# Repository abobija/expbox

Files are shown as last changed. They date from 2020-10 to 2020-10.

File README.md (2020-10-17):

# PCB Exposure Box [expbox]

This is repository of PCB Exposure Box [expbox] which uses PIC16F886 for it's brain and shows the time on display made up out of four seven-segment led modules.

Because display is made up out of 4 digits, I have decided to limit **maximum exposure time**, that can be set, to **1 hour** (**59m59s**). Even 1 hour is more than enough, because exposure process takes no more than maximum 10 to 15 minutes.

After the countdown comes to zero, finish of exposure process will be signalized with 1 second of high frequency tone.

### Demo

Making of Exposure Box ... *PCB diy* (https://www.youtube.com/watch?v=g0XoKE_xRvM)

## Microcontroller

Microcontroller used in this project is [**PIC16F886**](https://www.microchip.com/wwwproducts/en/PIC16F886) produced by [Microchip](https://www.microchip.com) company. This MCU has three timers and each timer is assigned to a separated task. **Timer0** is responsible for multiplexing four seven-segment led modules. **Timer1** is shared between tasks for precise time measuring and buttons debouncing. And last, but not least, **Timer2** is in charge of driving piezo speaker with **P**ulse **W**ide **M**odulated signal.

The controller uses an **internal oscillator** and it's set to maximum frequency of **8 MHz**.

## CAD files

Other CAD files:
sketchup/expbox.skp

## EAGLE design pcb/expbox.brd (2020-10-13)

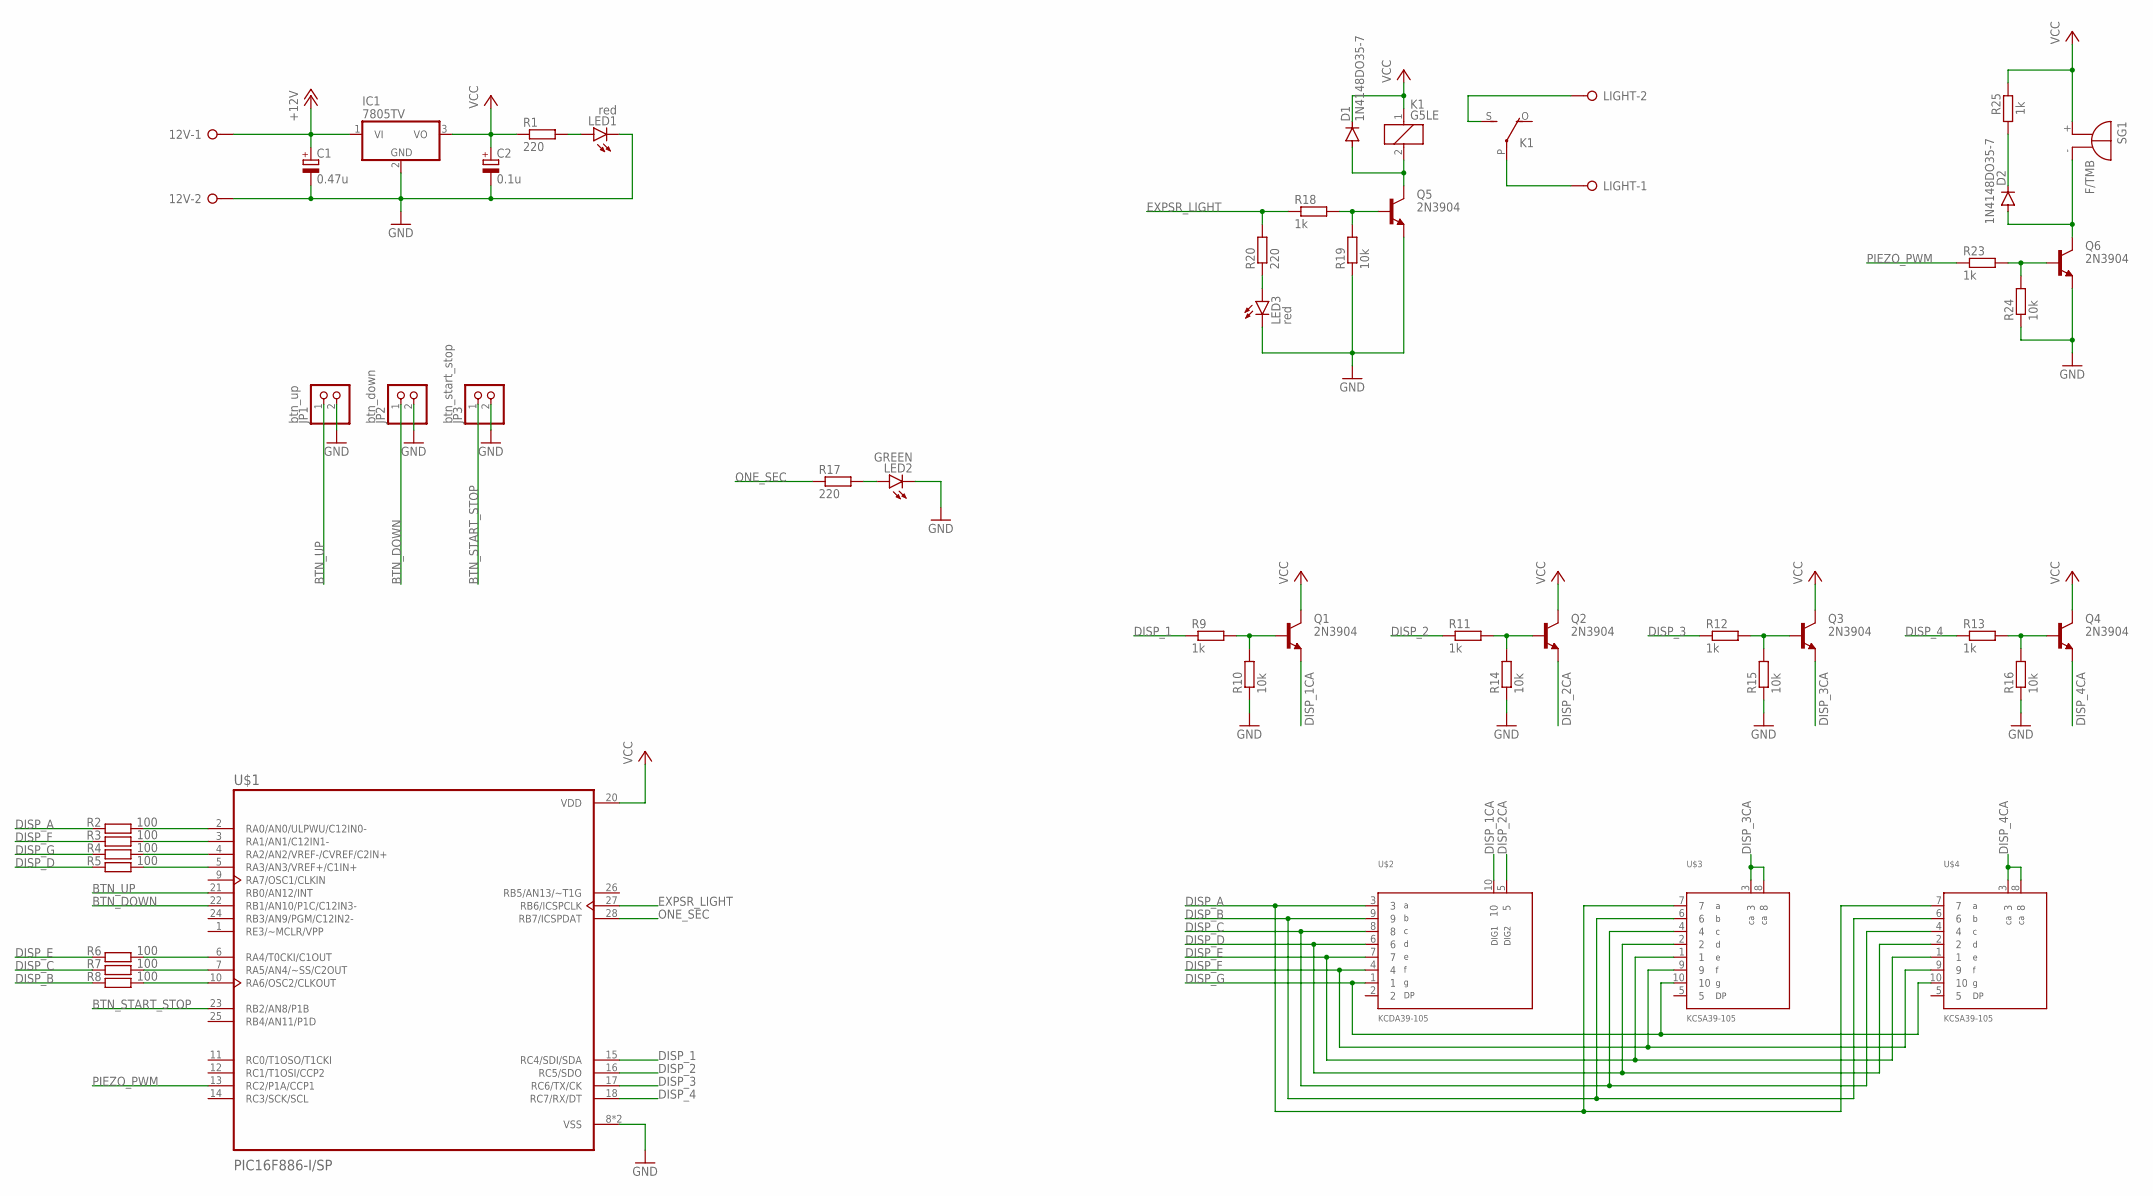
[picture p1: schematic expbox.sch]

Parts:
12V: W237-02P; W237-132
C1: 0.47u; E2,5-5
C2: 0.1u; E2-4
D1, D2: 1N4148DO35-7; DO35-7
IC1: 7805TV; TO220V
JP1: btn_up; 1X02
JP2: btn_down; 1X02
JP3: btn_start_stop; 1X02
K1: G5LE
LED1, LED3: red; LED3MM
LED2: GREEN; 1206
LIGHT: W237-02P; W237-132
Q1, Q2, Q3, Q4, Q5, Q6: 2N3904; SOT23-BEC
R1, R17, R20: 220; R0805
R2, R3, R4, R5, R6, R7, R8: 100; M1206
R9, R11, R12, R13, R18, R23, R25: 1k; R0805
R10, R14, R15, R16, R19, R24: 10k; R0805
SG1: F/TMB
U$1: PIC16F886-I/SP; DIP762W46P254L3467H457Q28
U$2: KCDA39-105
U$3, U$4: KCSA39-105

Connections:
+12V: 12V.1, C1.+, IC1.1 (VI)
BTN_DOWN: JP2.1, U$1.22 (RB1/AN10/P1C/C12IN3-)
BTN_START_STOP: JP3.1, U$1.23 (RB2/AN8/P1B)
BTN_UP: JP1.1, U$1.21 (RB0/AN12/INT)
DISP_1: R9.1, U$1.15 (RC4/SDI/SDA)
DISP_1CA: Q1.E, U$2.10
DISP_2: R11.1, U$1.16 (RC5/SDO)
DISP_2CA: Q2.E, U$2.5
DISP_3: R12.1, U$1.17 (RC6/TX/CK)
DISP_3CA: Q3.E, U$3.3, U$3.8
DISP_4: R13.1, U$1.18 (RC7/RX/DT)
DISP_4CA: Q4.E, U$4.3, U$4.8
DISP_A: R2.1, U$2.3, U$3.7, U$4.7
DISP_B: R8.1, U$2.9, U$3.6, U$4.6
DISP_C: R7.1, U$2.8, U$3.4, U$4.4
DISP_D: R5.1, U$2.6, U$3.2, U$4.2
DISP_E: R6.1, U$2.7, U$3.1, U$4.1
DISP_F: R3.1, U$2.4, U$3.9, U$4.9
DISP_G: R4.1, U$2.1, U$3.10, U$4.10
EXPSR_LIGHT: R18.1, R20.2, U$1.27 (RB6/ICSPCLK)
GND: 12V.2, C1.-, C2.-, IC1.2 (GND), JP1.2, JP2.2, JP3.2, LED1.K (C), LED2.C, LED3.K (C), Q5.E, Q6.E, R10.1, R14.1, R15.1, R16.1, R19.1, R24.1, U$1.8 (VSS), U$1.19 (VSS)
unnamed: LED1.A, R1.2
unnamed: R2.2, U$1.2 (RA0/AN0/ULPWU/C12IN0-)
unnamed: R3.2, U$1.3 (RA1/AN1/C12IN1-)
unnamed: R4.2, U$1.4 (RA2/AN2/VREF-/CVREF/C2IN+)
unnamed: R5.2, U$1.5 (RA3/AN3/VREF+/C1IN+)
unnamed: R6.2, U$1.6 (RA4/T0CKI/C1OUT)
unnamed: R7.2, U$1.7 (RA5/AN4/~SS/C2OUT)
unnamed: R8.2, U$1.10 (RA6/OSC2/CLKOUT)
unnamed: Q2.B, R11.2, R14.2
unnamed: Q1.B, R9.2, R10.2
unnamed: Q3.B, R12.2, R15.2
unnamed: Q4.B, R13.2, R16.2
unnamed: LED2.A, R17.2
unnamed: K1.S, LIGHT.2
unnamed: Q5.B, R18.2, R19.2
unnamed: D1.A, K1.2, Q5.C
unnamed: K1.P, LIGHT.1
unnamed: LED3.A, R20.1
unnamed: D2.A, Q6.C, SG1.-
unnamed: Q6.B, R23.2, R24.2
unnamed: D2.C, R25.1
ONE_SEC: R17.1, U$1.28 (RB7/ICSPDAT)
PIEZO_PWM: R23.1, U$1.13 (RC2/P1A/CCP1)
VCC: C2.+, D1.C, IC1.3 (VO), K1.1, Q1.C, Q2.C, Q3.C, Q4.C, R1.1, R25.2, SG1.+, U$1.20 (VDD)

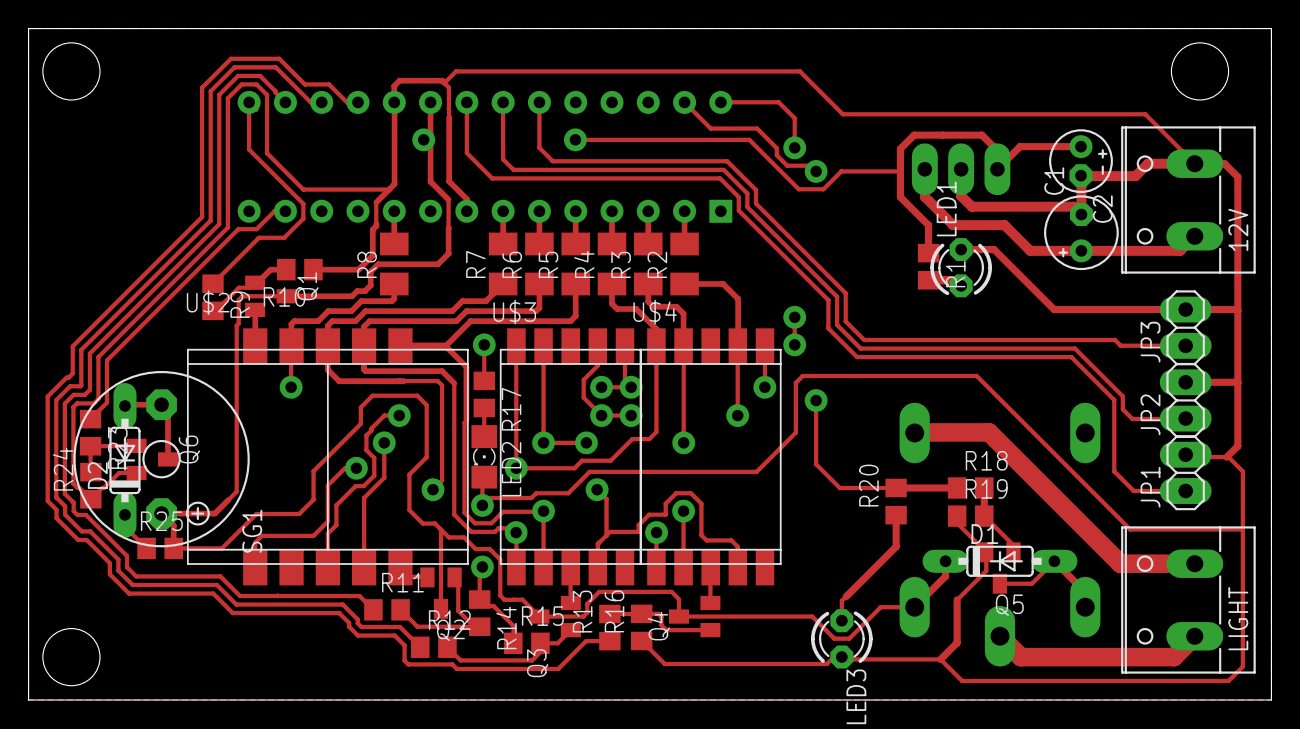
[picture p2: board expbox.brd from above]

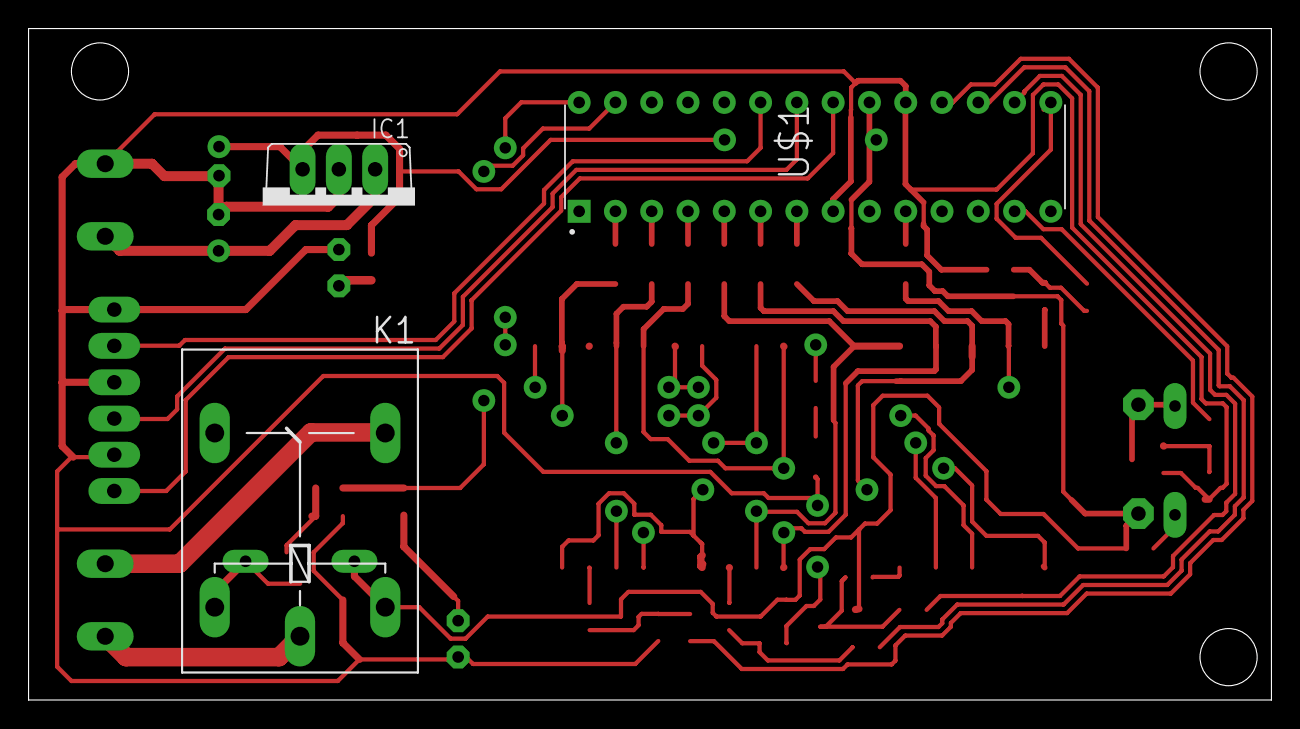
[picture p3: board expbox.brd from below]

Board: 2 copper layers, 87.0 x 47.0 mm, 48 parts (3 on the bottom side), 45 nets.

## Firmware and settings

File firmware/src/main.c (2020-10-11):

#include "main.h"

static xTime time = { 0, 0 };
static xTime time_backup;
static xTime time_in_eeprom;

static bool countdown_running = false;

static sbit one_sec_led_tris at TRISB.B7;
static sbit one_sec_led at PORTB.B7;
static sbit exposure_light_tris at TRISB.B6;
static sbit exposure_light at PORTB.B6;

void main() {
    // Set the internal oscillator frequency
#if(__FOSC__ == 8000)
    OSCCON |= 0x70; // 8 MHz
#elif(__FOSC__ == 4000)
    OSCCON |= 0x60; // 4 MHz
#elif(__FOSC__ == 2000)
    OSCCON |= 0x50; // 2 MHz
#endif

    INTCON = 0x00;  // Disable all interupts
    
    ANSEL = 0x00;   // All pins
    ANSELH = 0x00;  // are digital I/O

    one_sec_led_tris = 0;
    one_sec_led = OFF;
    
    exposure_light_tris = 0;
    exposure_light = OFF;

    read_time_from_eeprom();

    tmr_init();
    tmr_one_sec_callback = &one_sec_tick;
    
    buttons_init();
    buttons_up_callback = &button_up_handler;
    buttons_down_callback = &button_down_handler;
    buttons_start_stop_callback = &button_start_stop_handler;
    
    disp_init(&time);
    
    piezo_init();
    
    INTCON.GIE = 1; // Enable global interrupts
    
    while(true) {
        tmr_run();
        buttons_read();
        disp_show();
    }
}

void interrupt() {
    if(TMR1IF_bit) {
        tmr_timer_interrupt_handler();
        buttons_interrupt_handler();
        TMR1IF_bit = LOW;
    }

    disp_interrupt_handler();
}

void start_countdown() {
    if(countdown_running || xtime_is_zero(&time))
        return;

    buttons_disable_up_down();
    save_time_to_eeprom();
    xtime_copy(&time, &time_backup);
    exposure_light = ON;
    countdown_running = true;
}

void stop_countdown() {
    if(! countdown_running)
        return;

    exposure_light = OFF;
    xtime_copy(&time_backup, &time);
    buttons_enable_up_down();
    countdown_running = false;
}

void one_sec_tick() {
    one_sec_led = ~one_sec_led;
   
    if(piezo_is_on) {
        piezo_off();
    }
   
    if(countdown_running) {
        if(xtime_is_zero(&time)) {
            stop_countdown();
            piezo_on();
        } else {
            xtime_dec(&time);
        }
    }
}

void button_up_handler() {
    xtime_inc(&time);
}

void button_down_handler() {
    xtime_dec(&time);
}

void button_start_stop_handler() {
    if(countdown_running) {
        stop_countdown();
    } else {
        start_countdown();
    }
}

void save_time_to_eeprom() {
    if(xtime_is_same_as(&time, &time_in_eeprom)) {
        return;
    }

    EEPROM_Write(EEPROM_ADDR_MINUTES, time.min);
    EEPROM_Write(EEPROM_ADDR_SECONDS, time.sec);
    
    xtime_copy(&time, &time_in_eeprom);
}

void read_time_from_eeprom() {
    time.min = EEPROM_Read(EEPROM_ADDR_MINUTES);
    time.sec = EEPROM_Read(EEPROM_ADDR_SECONDS);
    
    if(time.min >= 60)
        time.min = 0;
        
    if(time.sec >= 60)
        time.sec = 0;

    xtime_copy(&time, &time_in_eeprom);
}

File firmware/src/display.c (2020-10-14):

#include "display.h"

/*  COMMON ANODE
 *
 *  ---------------------------------------
 *  DISP: | . | b | c | e | d | g | f | a |
 *  ---------------------------------------
 *  PORT: | 7 | 6 | 5 | 4 | 3 | 2 | 1 | 0 |
 *  ---------------------------------------
 */
static uint8_t disp_nums[] = {
    0b10000100,
    0b10011111,
    0b10100010,
    0b10010010,
    0b10011001,
    0b11010000,
    0b11000000,
    0b10011110,
    0b10000000,
    0b10010000
};

static uint8_t disp_port_tris at TRISA;
static uint8_t disp_port at PORTA;

static sbit disp_mod_1_tris at TRISC.B4;
static sbit disp_mod_1 at PORTC.B4;
static sbit disp_mod_2_tris at TRISC.B5;
static sbit disp_mod_2 at PORTC.B5;
static sbit disp_mod_3_tris at TRISC.B6;
static sbit disp_mod_3 at PORTC.B6;
static sbit disp_mod_4_tris at TRISC.B7;
static sbit disp_mod_4 at PORTC.B7;

static xTime *time;

bool disp_mux_flag = HIGH;

void disp_init(xTime *_time) {
    time = _time;
    
    disp_port_tris = 0x00;
    disp_port = 0xFF;
    
    disp_mod_1_tris
        = disp_mod_2_tris
        = disp_mod_3_tris
        = disp_mod_4_tris = 0;
    
    disp_mod_1
        = disp_mod_2
        = disp_mod_3
        = disp_mod_4 = 0;

                         // TIMER0:
    OPTION_REG.T0CS = 0; // TMR0 source: Fosc/4
    OPTION_REG.PSA = 0;  // Assign prescaler to tmr0
    
                         // Set prescaler
#if(__FOSC__ == 8000)
    OPTION_REG.PS2 = 0;  //
    OPTION_REG.PS1 = 1;  //
    OPTION_REG.PS0 = 1;  // 1:16
#elif(__FOSC__ == 4000)
    OPTION_REG.PS2 = 0;  //
    OPTION_REG.PS1 = 1;  //
    OPTION_REG.PS0 = 0;  // 1:8
#elif(__FOSC__ == 2000)
    OPTION_REG.PS2 = 0;  //
    OPTION_REG.PS1 = 0;  //
    OPTION_REG.PS0 = 1;  // 1:4
#endif

    TMR0 = 0;            // Reset tmr0
    INTCON.TMR0IE = 1;   // Enable tmr0 interrupt
}

void disp_show() {
    if(! disp_mux_flag)
        return;

    disp_mux_flag = LOW;
    disp_port = 0xFF;
    
    if(disp_mod_1) {
        disp_mod_1 = OFF;
        disp_mod_2 = ON;
        disp_port = disp_nums[time->min % 10];
    } else if(disp_mod_2) {
        disp_mod_2 = OFF;
        disp_mod_3 = ON;
        disp_port = disp_nums[time->sec / 10];
    } else if(disp_mod_3) {
        disp_mod_3 = OFF;
        disp_mod_4 = ON;
        disp_port = disp_nums[time->sec % 10];
    } else {
        disp_mod_4 = OFF;
        disp_mod_1 = ON;
        disp_port = disp_nums[time->min / 10];
    }
}

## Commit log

2020-10-05 Initial firmware commit
    [expbox.cfg]
2020-10-06 Enable interrupt-on-change and weak pull-ups on port B
2020-10-06 Revert int-on-change during constatly entering in interrupt
    [main.c]
2020-10-06 Make display timer interrupt handler function more generic
2020-10-06 One second counter moved to Timer1 and display multiplexing stays on Timer0
2020-10-07 Timer source files and corresponding foos for init and interrupt handler
2020-10-07 Buttons source files initial commit
2020-10-07 Configured Tmr2 for buttons
2020-10-07 Set internal osc freq according to predefined constant __FOSC__
    Set prescalers and all project timings according to __FOSC__
    Supported project freqs are 8, 4 and 2 [MHz]
    If unsupported frequency are choosen, preprocessor error will be risen
    [display.c, main.c]
2020-10-07 buttons_scan renamed to buttons_read
2020-10-07 Change buttons timer(2) prescaler from 1:16 to 1:4
2020-10-07 Implemented buttons debouncing algorithm
2020-10-07 Introducted xtime. Local xtime var attached to display. Increment/Decrement time handlers assign to corresponding buttons
2020-10-08 Buttons burst mode implemented
    Freq raised from 4 to 8MHz bcs display flicker at 4MHz while button is in burst mode
2020-10-08 Countdown mechanism. Disable up/down buttons while countdown.
2020-10-11 Buttons debouncing moved to Timer1 (which is shared now with countdown)
2020-10-12 PCB Eagle files
    [expbox.brd, expbox.sch]
2020-10-13 Replace buzzer with one with wider legs
    [expbox.brd, expbox.sch]
2020-10-15 Sketchup 3d model
    [expbox.skp]
